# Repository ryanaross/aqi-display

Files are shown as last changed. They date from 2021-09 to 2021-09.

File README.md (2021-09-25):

# AQI Display

A small box which will display the **Air Quality Index** based on the US EPA formula, using a $15 sensor and $10 microcontroller and display. As the AQI climbs, the background color changes, matching the colors used on [PurpleAir](https://map.purpleair.com/). The display is a 1.1" TFT, bright enough to be seen in daylight from across a large room.

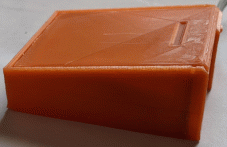
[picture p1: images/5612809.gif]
t-display image


### Features
* 30 seconds of data gathering and averaging of particle count to calculate AQI
* Color changing background based on AQI value
* Displays latest calculated value every 1 minute for the first 30 minutes. Then goes into a **Sleep Mode** to preserve the sensors fan, calculating a new AQI value every 30 minutes.
* Written in micropython, everything is easily configurable.
* Front button to begin gathering on demand
* Can be made portable with the use of a USB Power Bank
## Assembly

### Parts Required:
1. LILYGO® TTGO T-Display ESP32 [aliexpress](https://lilygo.aliexpress.com/store/2090076/search?SearchText=esp32+t-display)

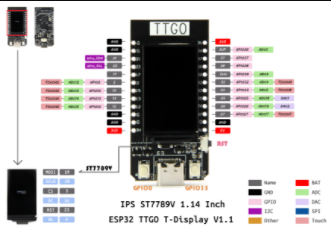
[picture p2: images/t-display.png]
t-display image


2. Plantower PMS7003 Air Quality Sensor + G7 Adapter [aliexpress](https://www.aliexpress.com/wholesale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)

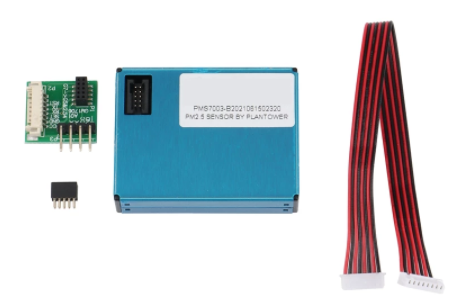
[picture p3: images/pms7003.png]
t-display image


### Software

Easiest way to setup the software is to hook up the T-Display to a computer running [Thonny](https://thonny.org/) and follow [these instructions](https://docs.micropython.org/en/latest/esp32/tutorial/intro.html) to flash [this custom firmware](https://github.com/russhughes/st7789_mpy/tree/master/firmware/T-DISPLAY), which includes drivers for writing to the display included with the T-Display device.

Then you can copy to the device all the `*.py` files from this repository and customize them if required.

### Hardware

Attach the G7 Adapter to the PMS7003 sensor, it will only fit one way. Connect the included cable to the adapter and cut off the other end to expose the wires. Strip, connect and solder the following connections:

| PMS7003 | T-Display |
| --- | --- |
| VCC | 5V |
| GND | G |
| RX | 26 |
| TX | 25 |

The T-Display schematic can be found [here](https://user-images.githubusercontent.com/25242404/79798978-70c1bc80-8362-11ea-89e7-cee3a98e8508.png).

### Case
The two components can be taped together quite easily. But if you have access to a 3d printer you can use the included STL files (in the `case/` directory) to print a case and fit the components inside. It uses a sliding dovetail top which can be printed separately.

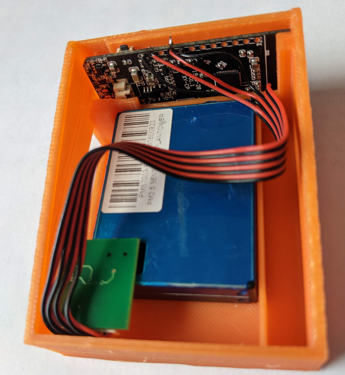
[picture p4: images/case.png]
case
]

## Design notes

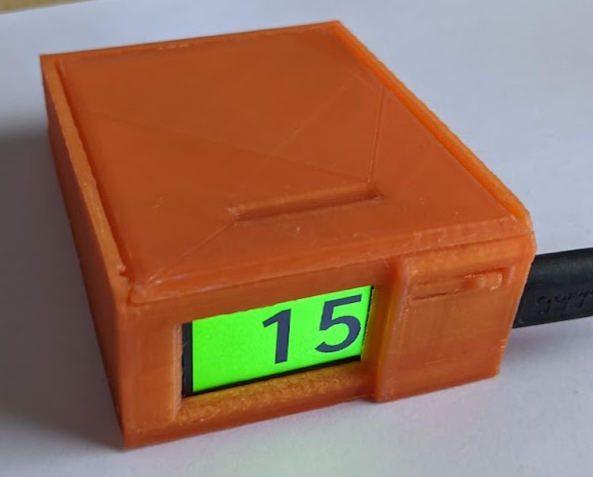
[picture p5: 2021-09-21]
images/aqi-display.png

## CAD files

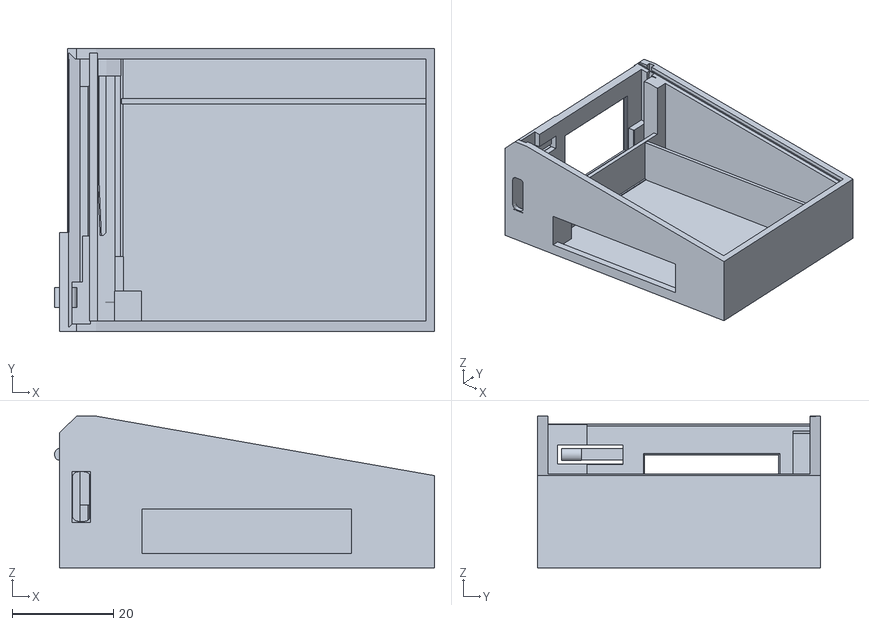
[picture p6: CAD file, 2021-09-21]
case/aqi_display.stl
75.1 x 55.9 x 30.0

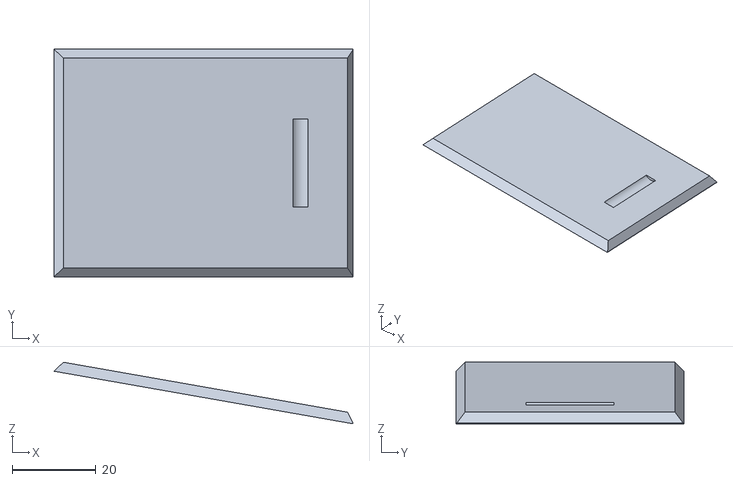
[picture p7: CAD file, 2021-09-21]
case/aqi_display_top.stl
71.4 x 54.3 x 14.7

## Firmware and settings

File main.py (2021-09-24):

from machine import Pin, SPI
from pms7003 import Pms7003
from aqi_calc import AQI
import aqi_font
import aqi_calc
import time
import st7789  # custom firmware from https://github.com/russhughes/st7789_mpy

# How long to warm up fan before beginning to gather data
STARTUP_SEC = 60
# How long to do 1 minute refreshes before switching into Sleep Mode
SLEEP_MODE_SWITCH_SEC = 1800
# How many seconds to put the sensor to sleep between sleeps during Sleep Mode
SLEEP_MODE_SEC = 1800

# Current state one of `warming_up`, `gathering_data`, `sleeping`, `waiting`
state = "warming_up"
buttonPushed = False

# initialize components
pms = Pms7003()

spi = SPI(1, baudrate=30000000, sck=Pin(18), mosi=Pin(19))
tft = st7789.ST7789(
    spi,
    135,
    240,
    reset=Pin(23, Pin.OUT),
    cs=Pin(5, Pin.OUT),
    dc=Pin(16, Pin.OUT),
    backlight=Pin(4, Pin.OUT),
    rotation=1)
tft.init()

# record startup time
startTime = time.time()

# Let the sensor warm and display a progress bar


def wakeUp():
    global tft, pms, state

    state = "warming_up"
    print("Waking up.")
    pms.wakeup()
    tft.fill(st7789.BLACK)
    count = 0
    while count < STARTUP_SEC:
        count = count + 1
        tft.fill_rect(0, 0, int(count*(240/STARTUP_SEC)), 135, st7789.GREEN)
        time.sleep(1)

# Gathers PM2.5 data for 30 seconds


def gatherData():
    global pms, tft, state

    state = "gathering_data"
    print("Gathering data.")
    count = 0
    pms2s = []
    while count < 30:
        count = count + 1
        pms_data = pms.read()
        pms2s.append(pms_data['PM2_5_ATM'])
        tft.fill_rect(0, 0, int(count*(240/30)), 10, st7789.BLUE)
        tft.fill_rect(0, 125, int(count*(240/30)), 10, st7789.BLUE)
        time.sleep(1)
    print(f"PMS2.5: {pms2s}")
    pms2 = sum(pms2s) / len(pms2s)
    aqi = AQI.aqi(pms2)
    print("AQI: " + str(int(aqi)))
    return aqi

# Display the given AQI (integer, required)


def displayAQI(aqi):
    global tft

    # Pick a foreground and background color based on AQI
    if aqi < 50:
        # green to yellow, text black
        fillColor = st7789.color565(int(aqi*5.15), 255, 0)
        textColor = st7789.BLACK
    elif aqi >= 50 and aqi < 150:
        # yellow to red, text black
        remainder = aqi - 49
        fillColor = st7789.color565(255, int(255-(remainder*2.55)), 0)
        textColor = st7789.BLACK
    elif aqi >= 150 and aqi < 250:
        # red to black, text white
        remainder = aqi - 149
        fillColor = st7789.color565(int(255-(remainder*2.55)), 0, 0)
        textColor = st7789.WHITE
    else:
        # Ouch
        fillColor = st7789.BLACK
        textColor = st7789.YELLOW

    # Add string padding for right justification
    if aqi < 10:
        strAQI = "  " + str(aqi)
    elif aqi < 100:
        strAQI = " " + str(aqi)
    else:
        strAQI = str(aqi)

    # Display selected background color and AQI
    tft.fill(fillColor)
    tft.write(aqi_font, strAQI, 0, int(
        (135-103)/2), textColor, fillColor)


def handleTopButton(pin):
    global buttonPushed, state

    if state in ["warming_up", "gathering_data"]:
        print(f"Button was pushed while in a bad state: {state}")
    else:
        buttonPushed = True
        print("Button has been pushed")


def main():
    global state, buttonPushed

    while True:
        aqi = gatherData()

        displayAQI(int(aqi))

        currentTime = time.time()
        if currentTime - startTime < SLEEP_MODE_SWITCH_SEC:
            state = "waiting"
            wait = 0
            while wait < 30:
                wait = wait + 1
                if buttonPushed == True:
                    # Cancel the wait and start gathering data immediatly
                    buttonPushed = False
                    break
                time.sleep(1)
        else:
            # Sleep Mode - puts the sensor to sleep periodically to preserve the life of the fan
            state = "sleeping"
            pms.sleep()
            print(f"Sleeping for {SLEEP_MODE_SEC-60} seconds.")
            wait = 0
            while wait < (SLEEP_MODE_SEC-60):
                wait = wait + 1
                if buttonPushed == True:
                    # Cancel the wait and start gathering data immediatly
                    break
                time.sleep(1)
            if buttonPushed == True:
                buttonPushed = False
                # If the button was pushed, display startup progress bar again for immediate feedback
                wakeUp()
            else:
                state = "waiting"
                pms.wakeup()
                wait = 0
                while wait < STARTUP_SEC:
                    wait = wait + 1
                    if buttonPushed == True:
                        # Cancel the wait and start gathering data immediatly
                        buttonPushed = False
                        break
                    time.sleep(1)


topButton = Pin(35, Pin.IN)
topButton.irq(trigger=Pin.IRQ_RISING, handler=handleTopButton)

wakeUp()
main()

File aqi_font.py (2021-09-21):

# -*- coding: utf-8 -*-
# font2bitmap.py inconsolata-700.ttf 160 -s '0123456789 '

MAP = "0123456789 "
BPP = 1
HEIGHT = 103
MAX_WIDTH = 80
_WIDTHS = \
    b'\x50\x50\x50\x50\x50\x50\x50\x50\x50\x50\x50'

OFFSET_WIDTH = 3
_OFFSETS = \
    b'\x00\x00\x00\x00\x20\x30\x00\x40\x60\x00\x60\x90\x00\x80\xc0\x00'\
    b'\xa0\xf0\x00\xc1\x20\x00\xe1\x50\x01\x01\x80\x01\x21\xb0\x01\x41'\
    b'\xe0'

_BITMAPS =\
    b'\x00\x00\x00\x00\x3f\xfc\x00\x00\x00\x00\x00\x00\x00\x03\xff\xff'\
    b'\xc0\x00\x00\x00\x00\x00\x00\x0f\xff\xff\xf0\x00\x00\x00\x00\x00'\
    b'\x00\x3f\xff\xff\xfc\x00\x00\x00\x00\x00\x00\xff\xff\xff\xff\x00'\
    b'\x00\x00\x00\x00\x01\xff\xff\xff\xff\x80\x00\x00\x00\x00\x07\xff'\
    b'\xff\xff\xff\xc0\x00\x00\x00\x00\x0f\xff\xff\xff\xff\xf0\x00\x00'\
    b'\x00\x00\x1f\xff\xff\xff\xff\xf8\x00\x00\x00\x00\x3f\xff\xff\xff'\
    b'\xff\xfc\x00\x00\x00\x00\x3f\xff\xff\xff\xff\xfc\x00\x00\x00\x00'\
    b'\x7f\xff\xff\xff\xff\xfe\x00\x00\x00\x00\xff\xff\xff\xff\xff\xff'\
    b'\x00\x00\x00\x01\xff\xff\xff\xff\xff\xff\x80\x00\x00\x01\xff\xff'\
    b'\xff\xff\xff\xff\x80\x00\x00\x03\xff\xff\xe0\x07\xff\xff\xc0\x00'\
    b'\x00\x07\xff\xff\x80\x01\xff\xff\xe0\x00\x00\x07\xff\xff\x00\x00'\
    b'\xff\xff\xe0\x00\x00\x0f\xff\xfe\x00\x00\x7f\xff\xf0\x00\x00\x0f'\
    b'\xff\xfc\x00\x00\x3f\xff\xf0\x00\x00\x1f\xff\xf8\x00\x00\x1f\xff'\
    b'\xf0\x00\x00\x1f\xff\xf8\x00\x00\x1f\xff\xf8\x00\x00\x1f\xff\xf0'\
    b'\x00\x00\x0f\xff\xf8\x00\x00\x3f\xff\xe0\x00\x00\x0f\xff\xfc\x00'\
    b'\x00\x3f\xff\xe0\x00\x00\x07\xff\xfc\x00\x00\x3f\xff\xe0\x00\x00'\
    b'\x07\xff\xfc\x00\x00\x7f\xff\xc0\x00\x00\x03\xff\xfe\x00\x00\x7f'\
    b'\xff\xc0\x00\x00\x03\xff\xfe\x00\x00\x7f\xff\xc0\x00\x00\x07\xff'\
    b'\xfe\x00\x00\xff\xff\x80\x00\x00\x0f\xff\xff\x00\x00\xff\xff\x80'\
    b'\x00\x00\x0f\xff\xff\x00\x00\xff\xff\x80\x00\x00\x1f\xff\xff\x00'\
    b'\x00\xff\xff\x00\x00\x00\x3f\xff\xff\x00\x01\xff\xff\x00\x00\x00'\
    b'\x7f\xff\xff\x00\x01\xff\xff\x00\x00\x00\xff\xff\xff\x80\x01\xff'\
    b'\xff\x00\x00\x01\xff\xff\xff\x80\x01\xff\xff\x00\x00\x03\xff\xff'\
    b'\xff\x80\x01\xff\xff\x00\x00\x03\xff\xff\xff\x80\x01\xff\xfe\x00'\
    b'\x00\x07\xff\xff\xff\x80\x01\xff\xfe\x00\x00\x0f\xff\xff\xff\x80'\
    b'\x03\xff\xfe\x00\x00\x1f\xff\x7f\xff\x80\x03\xff\xfe\x00\x00\x3f'\
    b'\xff\x7f\xff\xc0\x03\xff\xfe\x00\x00\x7f\xfe\x7f\xff\xc0\x03\xff'\
    b'\xfe\x00\x00\x7f\xfc\x7f\xff\xc0\x03\xff\xfe\x00\x00\xff\xf8\x7f'\
    b'\xff\xc0\x03\xff\xfe\x00\x01\xff\xf0\x7f\xff\xc0\x03\xff\xfe\x00'\
    b'\x03\xff\xe0\x7f\xff\xc0\x03\xff\xfe\x00\x07\xff\xc0\x7f\xff\xc0'\
    b'\x03\xff\xfe\x00\x0f\xff\xc0\x7f\xff\xc0\x03\xff\xfe\x00\x1f\xff'\
    b'\x80\x7f\xff\xc0\x03\xff\xfe\x00\x1f\xff\x00\x7f\xff\xc0\x03\xff'\
    b'\xfe\x00\x3f\xfe\x00\x7f\xff\xc0\x03\xff\xfe\x00\x7f\xfc\x00\x7f'\
    b'\xff\xc0\x03\xff\xfe\x00\xff\xf8\x00\x7f\xff\xc0\x03\xff\xfe\x01'\
    b'\xff\xf8\x00\x7f\xff\xc0\x03\xff\xfe\x03\xff\xf0\x00\x7f\xff\xc0'\
    b'\x03\xff\xfe\x03\xff\xe0\x00\x7f\xff\xc0\x03\xff\xfe\x07\xff\xc0'\
    b'\x00\x7f\xff\xc0\x03\xff\xfe\x0f\xff\x80\x00\x7f\xff\xc0\x03\xff'\
    b'\xfe\x1f\xff\x00\x00\x7f\xff\xc0\x03\xff\xfe\x3f\xfe\x00\x00\x7f'\
    b'\xff\xc0\x03\xff\xfe\x7f\xfe\x00\x00\x7f\xff\xc0\x03\xff\xfe\xff'\
    b'\xfc\x00\x00\x7f\xff\xc0\x01\xff\xfe\xff\xf8\x00\x00\x7f\xff\x80'\
    b'\x01\xff\xff\xff\xf0\x00\x00\x7f\xff\x80\x01\xff\xff\xff\xe0\x00'\
    b'\x00\xff\xff\x80\x01\xff\xff\xff\xc0\x00\x00\xff\xff\x80\x01\xff'\
    b'\xff\xff\x80\x00\x00\xff\xff\x80\x01\xff\xff\xff\x80\x00\x00\xff'\
    b'\xff\x80\x01\xff\xff\xff\x00\x00\x00\xff\xff\x80\x00\xff\xff\xfe'\
    b'\x00\x00\x00\xff\xff\x00\x00\xff\xff\xfc\x00\x00\x01\xff\xff\x00'\
    b'\x00\xff\xff\xf8\x00\x00\x01\xff\xff\x00\x00\xff\xff\xf0\x00\x00'\
    b'\x01\xff\xff\x00\x00\xff\xff\xe0\x00\x00\x01\xff\xff\x00\x00\x7f'\
    b'\xff\xe0\x00\x00\x03\xff\xfe\x00\x00\x7f\xff\xc0\x00\x00\x03\xff'\
    b'\xfe\x00\x00\x7f\xff\xc0\x00\x00\x03\xff\xfe\x00\x00\x3f\xff\xe0'\
    b'\x00\x00\x07\xff\xfc\x00\x00\x3f\xff\xe0\x00\x00\x07\xff\xfc\x00'\
    b'\x00\x3f\xff\xf0\x00\x00\x0f\xff\xfc\x00\x00\x1f\xff\xf0\x00\x00'\
    b'\x0f\xff\xf8\x00\x00\x1f\xff\xf8\x00\x00\x1f\xff\xf8\x00\x00\x0f'\
    b'\xff\xf8\x00\x00\x1f\xff\xf0\x00\x00\x0f\xff\xfc\x00\x00\x3f\xff'\
    b'\xf0\x00\x00\x07\xff\xfe\x00\x00\x7f\xff\xe0\x00\x00\x07\xff\xff'\
    b'\x00\x00\xff\xff\xe0\x00\x00\x03\xff\xff\xc0\x03\xff\xff\xc0\x00'\
    b'\x00\x03\xff\xff\xf0\x0f\xff\xff\xc0\x00\x00\x01\xff\xff\xff\xff'\
    b'\xff\xff\x80\x00\x00\x00\xff\xff\xff\xff\xff\xff\x00\x00\x00\x00'\
    b'\xff\xff\xff\xff\xff\xff\x00\x00\x00\x00\x7f\xff\xff\xff\xff\xfe'\
    b'\x00\x00\x00\x00\x3f\xff\xff\xff\xff\xfc\x00\x00\x00\x00\x1f\xff'\
    b'\xff\xff\xff\xf8\x00\x00\x00\x00\x0f\xff\xff\xff\xff\xf0\x00\x00'\
    b'\x00\x00\x07\xff\xff\xff\xff\xe0\x00\x00\x00\x00\x03\xff\xff\xff'\
    b'\xff\xc0\x00\x00\x00\x00\x00\xff\xff\xff\xff\x00\x00\x00\x00\x00'\
    b'\x00\x7f\xff\xff\xfc\x00\x00\x00\x00\x00\x00\x1f\xff\xff\xf0\x00'\
    b'\x00\x00\x00\x00\x00\x03\xff\xff\xc0\x00\x00\x00\x00\x00\x00\x00'\
    b'\x3f\xfc\x00\x00\x00\x00\x00\x00\x00\x00\x00\x00\x00\x00\x00\x00'\
    b'\x00\x00\x00\x00\x07\xff\xe0\x00\x00\x00\x00\x00\x00\x00\x1f\xff'\
    b'\xe0\x00\x00\x00\x00\x00\x00\x00\x7f\xff\xe0\x00\x00\x00\x00\x00'\
    b'\x00\x01\xff\xff\xe0\x00\x00\x00\x00\x00\x00\x07\xff\xff\xe0\x00'\
    b'\x00\x00\x00\x00\x00\x0f\xff\xff\xe0\x00\x00\x00\x00\x00\x00\x3f'\
    b'\xff\xff\xe0\x00\x00\x00\x00\x00\x00\xff\xff\xff\xe0\x00\x00\x00'\
    b'\x00\x00\x03\xff\xff\xff\xe0\x00\x00\x00\x00\x00\x0f\xff\xff\xff'\
    b'\xe0\x00\x00\x00\x00\x00\x3f\xff\xff\xff\xe0\x00\x00\x00\x00\x00'\
    b'\xff\xff\xff\xff\xe0\x00\x00\x00\x00\x03\xff\xff\xff\xff\xe0\x00'\
    b'\x00\x00\x00\x0f\xff\xff\xff\xff\xe0\x00\x00\x00\x00\x1f\xff\xff'\
    b'\xff\xff\xe0\x00\x00\x00\x00\x0f\xff\xff\xff\xff\xe0\x00\x00\x00'\
    b'\x00\x0f\xff\xff\xff\xff\xe0\x00\x00\x00\x00\x0f\xff\xff\xff\xff'\
    b'\xe0\x00\x00\x00\x00\x07\xff\xff\xff\xff\xe0\x00\x00\x00\x00\x07'\
    b'\xff\xff\xff\xff\xe0\x00\x00\x00\x00\x07\xff\xfe\x7f\xff\xe0\x00'\
    b'\x00\x00\x00\x03\xff\xf0\x7f\xff\xe0\x00\x00\x00\x00\x03\xff\x80'\
    b'\x7f\xff\xe0\x00\x00\x00\x00\x03\xfe\x00\x7f\xff\xe0\x00\x00\x00'\
    b'\x00\x01\xf0\x00\x7f\xff\xe0\x00\x00\x00\x00\x01\x80\x00\x7f\xff'\
    b'\xe0\x00\x00\x00\x00\x00\x00\x00\x7f\xff\xe0\x00\x00\x00\x00\x00'\
    b'\x00\x00\x7f\xff\xe0\x00\x00\x00\x00\x00\x00\x00\x7f\xff\xe0\x00'\
    b'\x00\x00\x00\x00\x00\x00\x7f\xff\xe0\x00\x00\x00\x00\x00\x00\x00'\
    b'\x7f\xff\xe0\x00\x00\x00\x00\x00\x00\x00\x7f\xff\xe0\x00\x00\x00'\
    b'\x00\x00\x00\x00\x7f\xff\xe0\x00\x00\x00\x00\x00\x00\x00\x7f\xff'\
    b'\xe0\x00\x00\x00\x00\x00\x00\x00\x7f\xff\xe0\x00\x00\x00\x00\x00'\
    b'\x00\x00\x7f\xff\xe0\x00\x00\x00\x00\x00\x00\x00\x7f\xff\xe0\x00'\
    b'\x00\x00\x00\x00\x00\x00\x7f\xff\xe0\x00\x00\x00\x00\x00\x00\x00'\
    b'\x7f\xff\xe0\x00\x00\x00\x00\x00\x00\x00\x7f\xff\xe0\x00\x00\x00'\
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

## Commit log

2021-09-21 add case
    [aqi_display.stl, aqi_display_top.stl]
2021-09-21 case photo
